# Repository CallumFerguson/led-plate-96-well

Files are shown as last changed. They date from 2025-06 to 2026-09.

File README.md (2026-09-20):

# led-plate-96-well

control genetically engineered cells with light

## Description

PCB for running optogenetic experiments. Designed to shine light through the bottom of [clear bottom 96 well plates](https://www.thermofisher.com/order/catalog/product/152037) and activate light gated ion channels in genetically engineered cells.

Used for experiments in controlling cell maturation by changing the cell's resting membrane potential.

## PCB

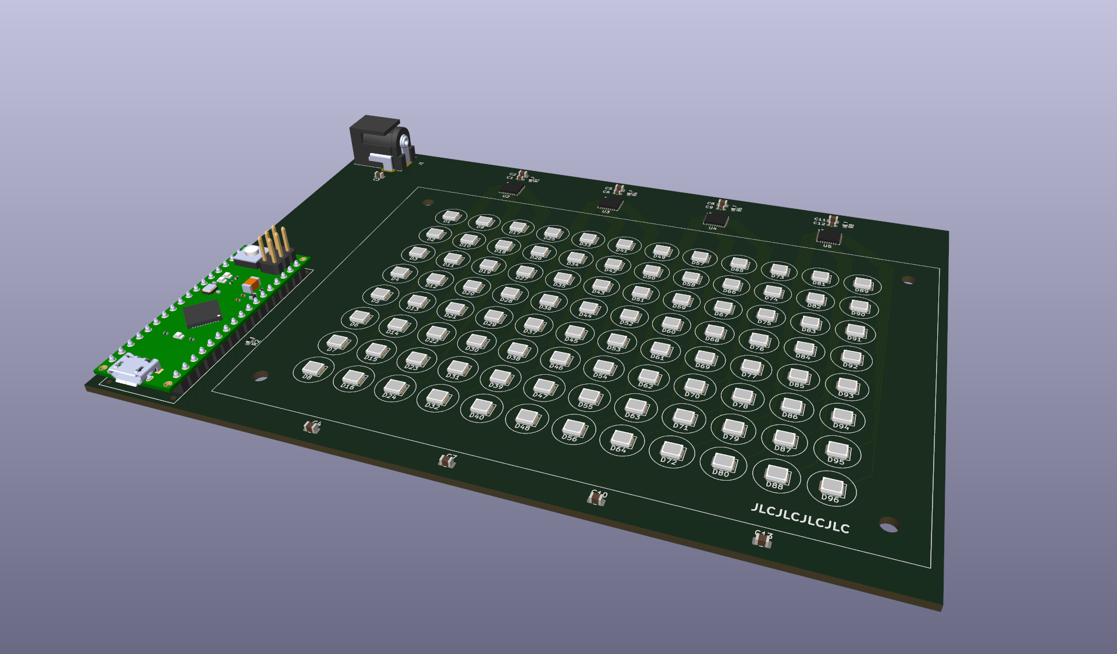
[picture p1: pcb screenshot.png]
3D view of the 96-well LED plate PCB


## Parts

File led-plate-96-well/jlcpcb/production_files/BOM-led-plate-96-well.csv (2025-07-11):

Comment | Designator | Footprint | LCSC | Quantity
2.49kΩ | R1,R4,R6,R8 | R_0402_1005Metric | C102924 | 4
100nF | C1,C12,C6,C9 | C_0603_1608Metric | C14663 | 4
100uF | C3 | C_1206_3216Metric | C15008 | 1
10uF | C10,C11,C13,C2,C4,C5,C7,C8 | C_0805_2012Metric | C15850 | 8
TLC5947RHB | U2,U3,U4,U5 | QFN-32-1EP_5x5mm_P0.5mm_EP3.45x3.45mm | C181402 | 4
10kΩ | R2 | R_0603_1608Metric | C25804 | 1
LED | D1,D10,D11,D12,D13,D14,D15,D16,D17,D18,D19,D2,D20,D21,D22,D23,D24,D25,D26,D27,D28,D29,D3,D30,D31,D32,D33,D34,D35,D36,D37,D38,D39,D4,D40,D41,D42,D43,D44,D45,D46,D47,D48,D49,D5,D50,D51,D52,D53,D54,D55,D56,D57,D58,D59,D6,D60,D61,D62,D63,D64,D65,D66,D67,D68,D69,D7,D70,D71,D72,D73,D74,D75,D76,D77,D78,D79,D8,D80,D81,D82,D83,D84,D85,D86,D87,D88,D89,D9,D90,D91,D92,D93,D94,D95,D96 | LED_PLCC_2835 | C440449 | 96

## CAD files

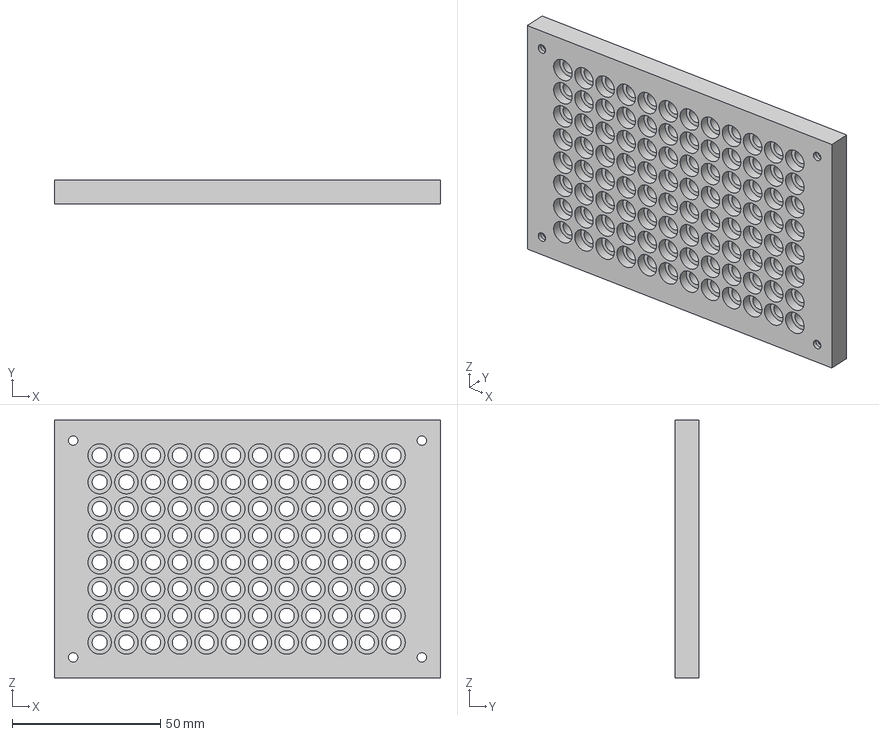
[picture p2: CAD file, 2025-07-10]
led-plate-96-well/components/plate_adapater_96_well/Opto Plate v10.step
130.0 x 8.13 x 86.8 mm

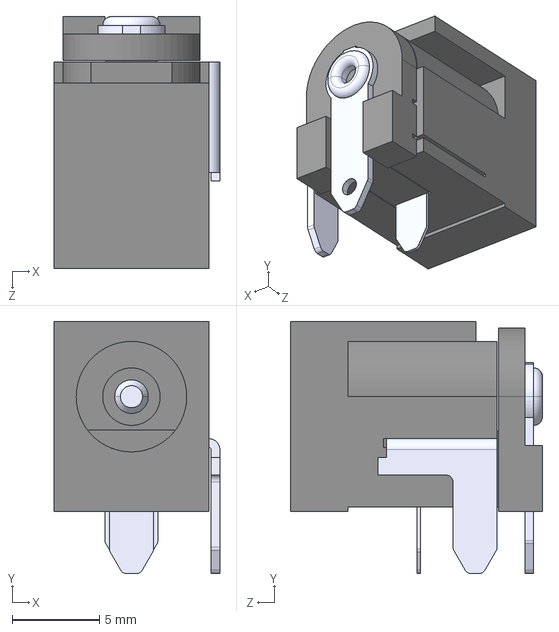
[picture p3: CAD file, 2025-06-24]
led-plate-96-well/components/RAPC722X/RAPC722X.step
9.53 x 14.5 x 14.5 mm

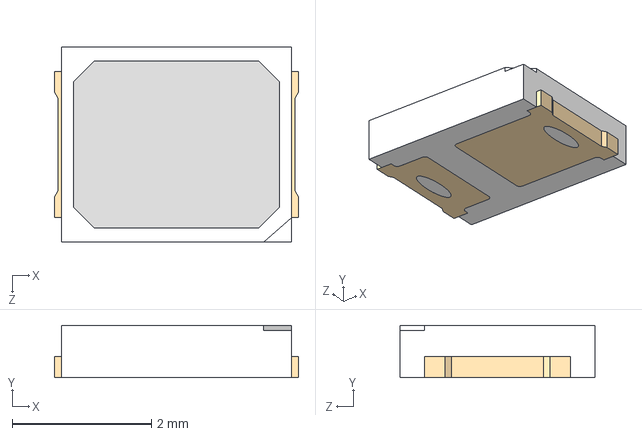
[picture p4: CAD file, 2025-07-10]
led-plate-96-well/components/SMD2835/SMD2835.STEP
3.50 x 0.75 x 2.80 mm

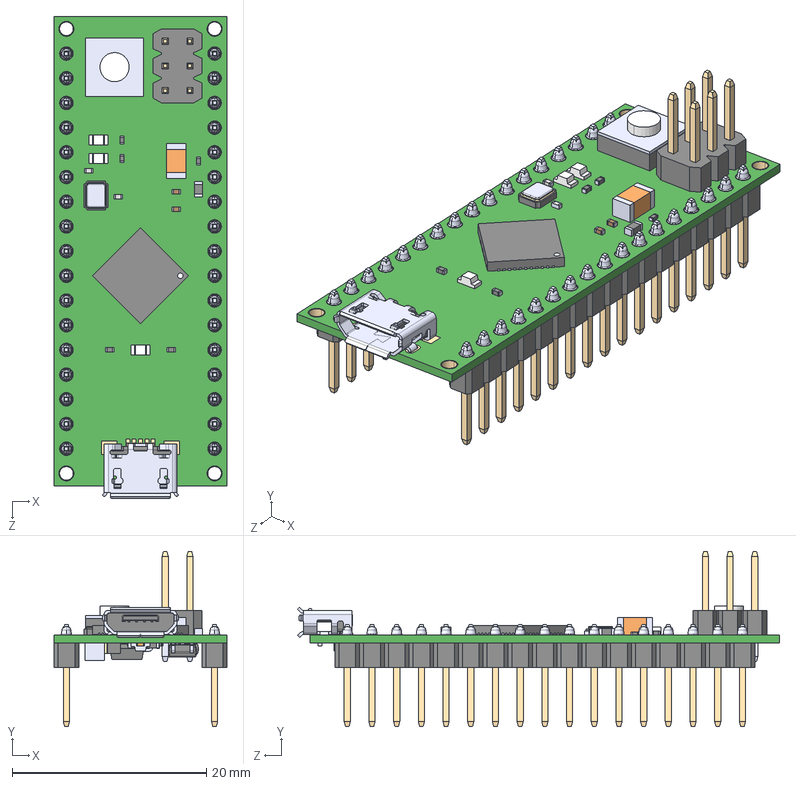
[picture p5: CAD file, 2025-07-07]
led-plate-96-well/components/arduino_micro/A000053.step
17.8 x 18.0 x 49.6 mm
Arduino Micro_Board
10118193-0001LF
ATMEGA32U4-XUMU_ATMEGA32U4-XUMU
CG0603MLC-05E_CG0603MLC-05E x 2
FDN340P
LP2985-33DBVR_LP2985-33DBVR
MC33269ST_MC33269ST
MF-MSMF050-2_MF-MSMF050-2
PMV48XP_PMV48XP

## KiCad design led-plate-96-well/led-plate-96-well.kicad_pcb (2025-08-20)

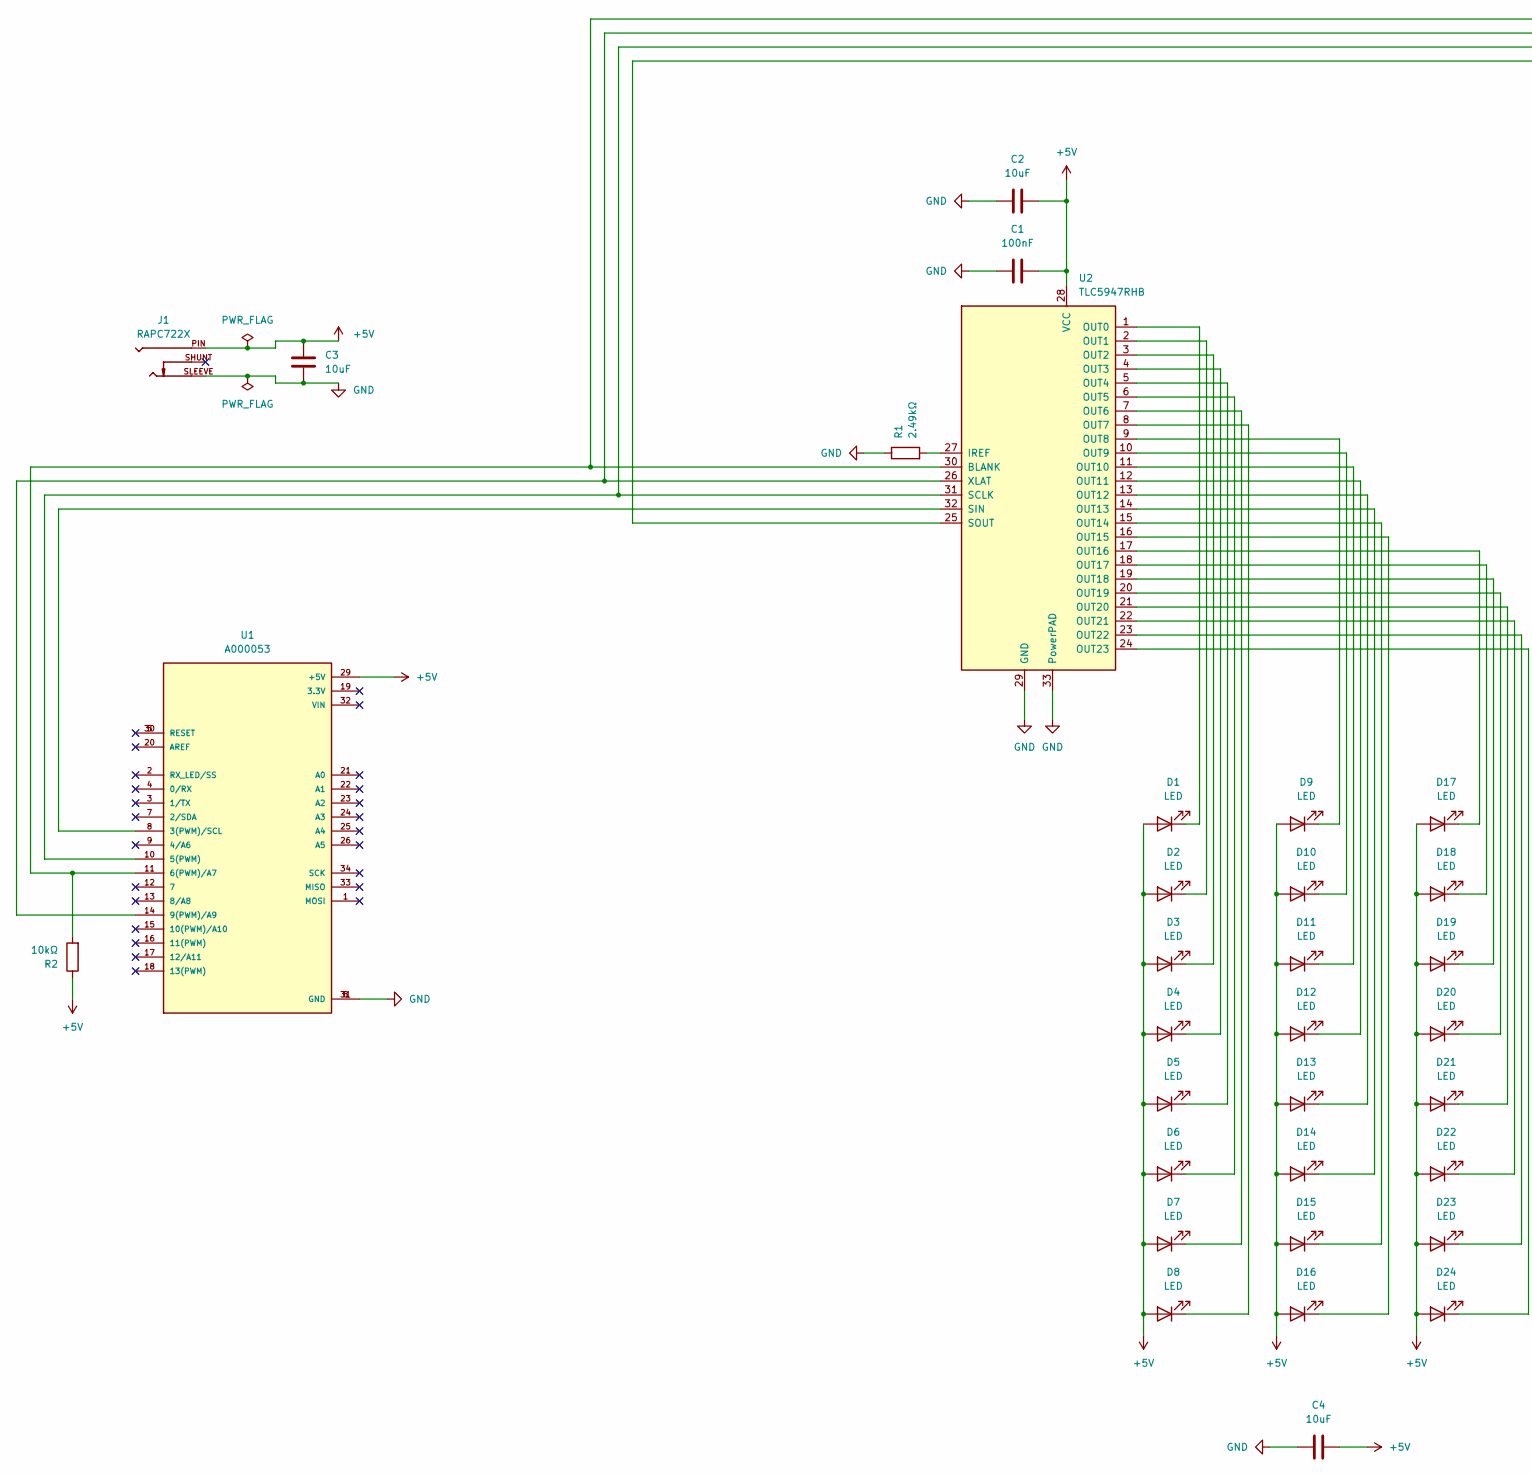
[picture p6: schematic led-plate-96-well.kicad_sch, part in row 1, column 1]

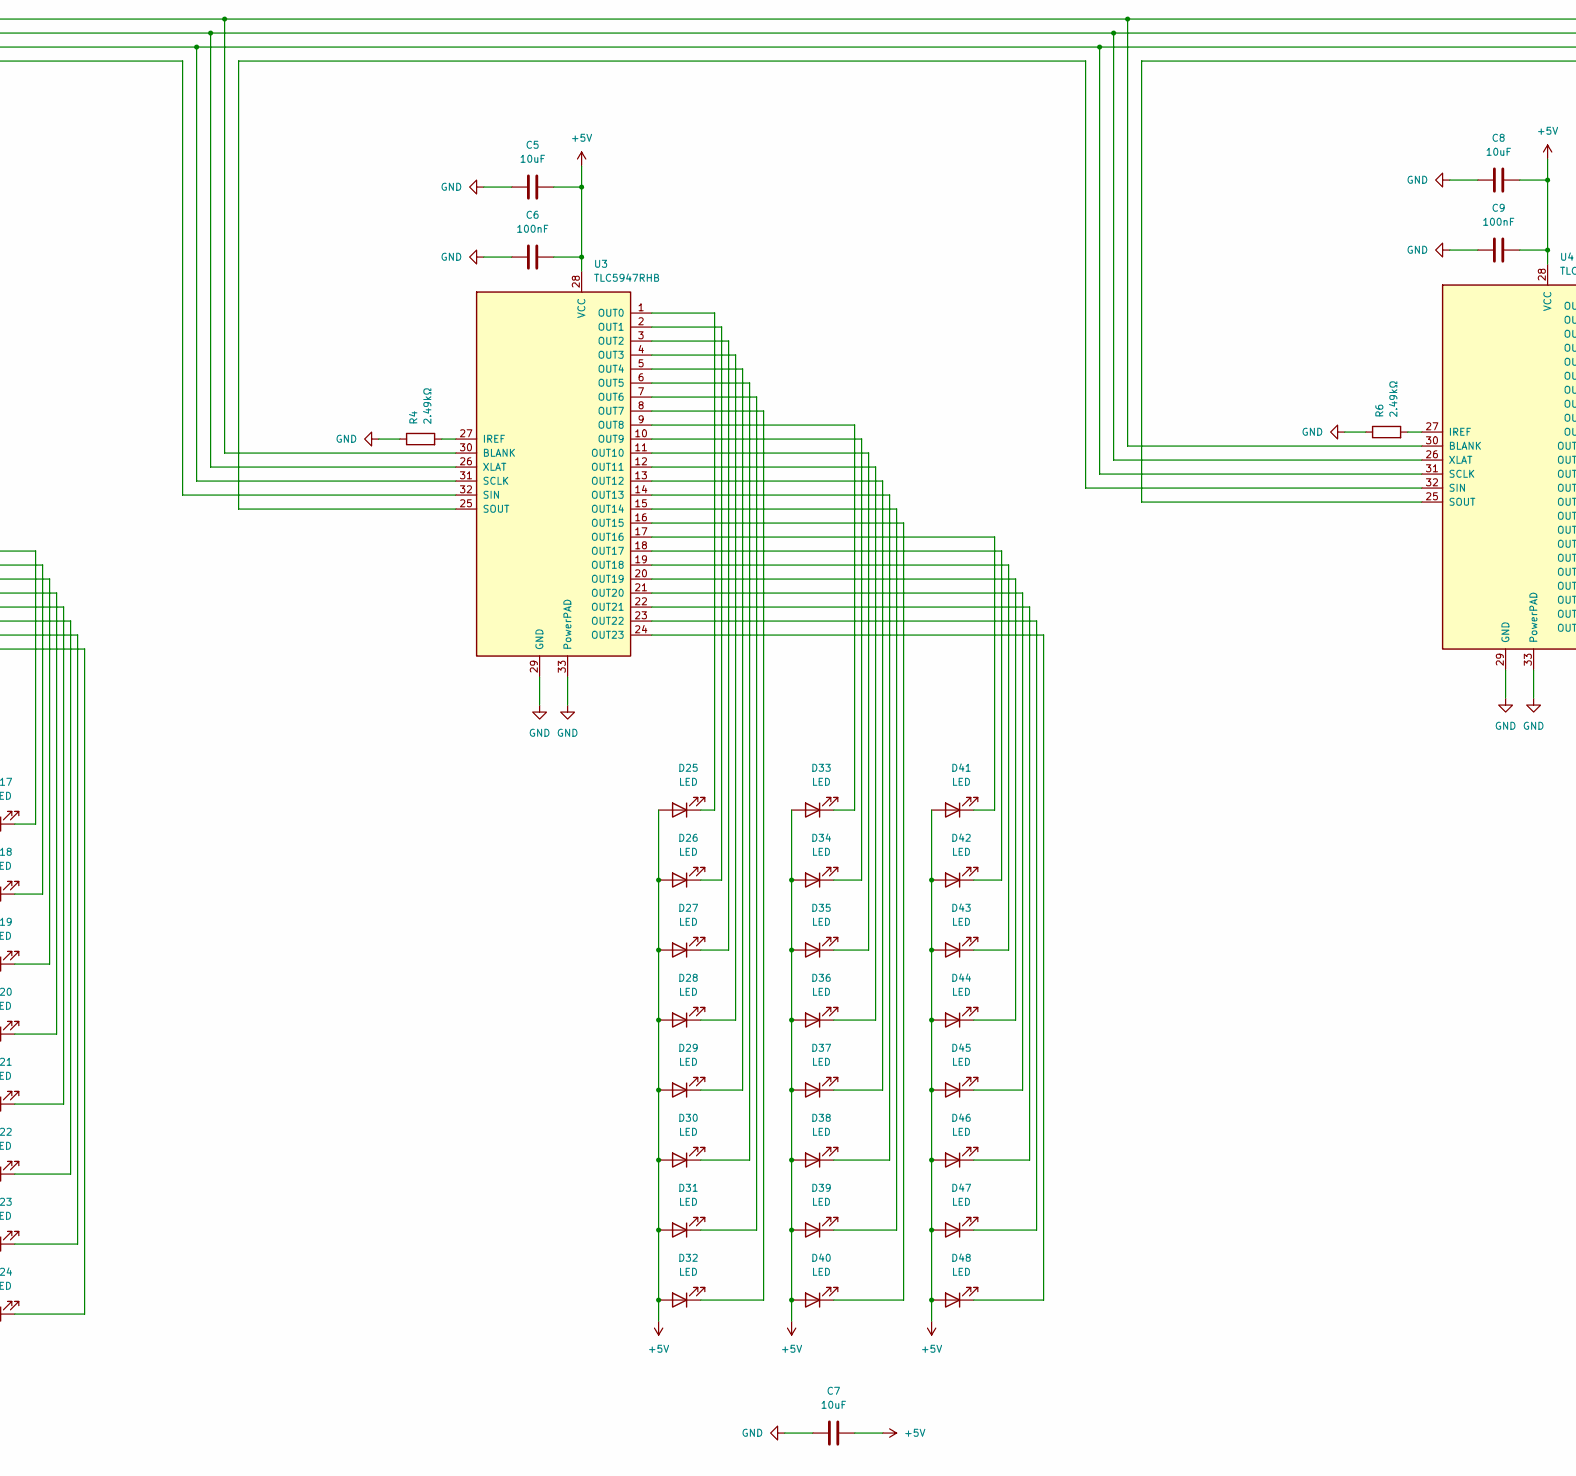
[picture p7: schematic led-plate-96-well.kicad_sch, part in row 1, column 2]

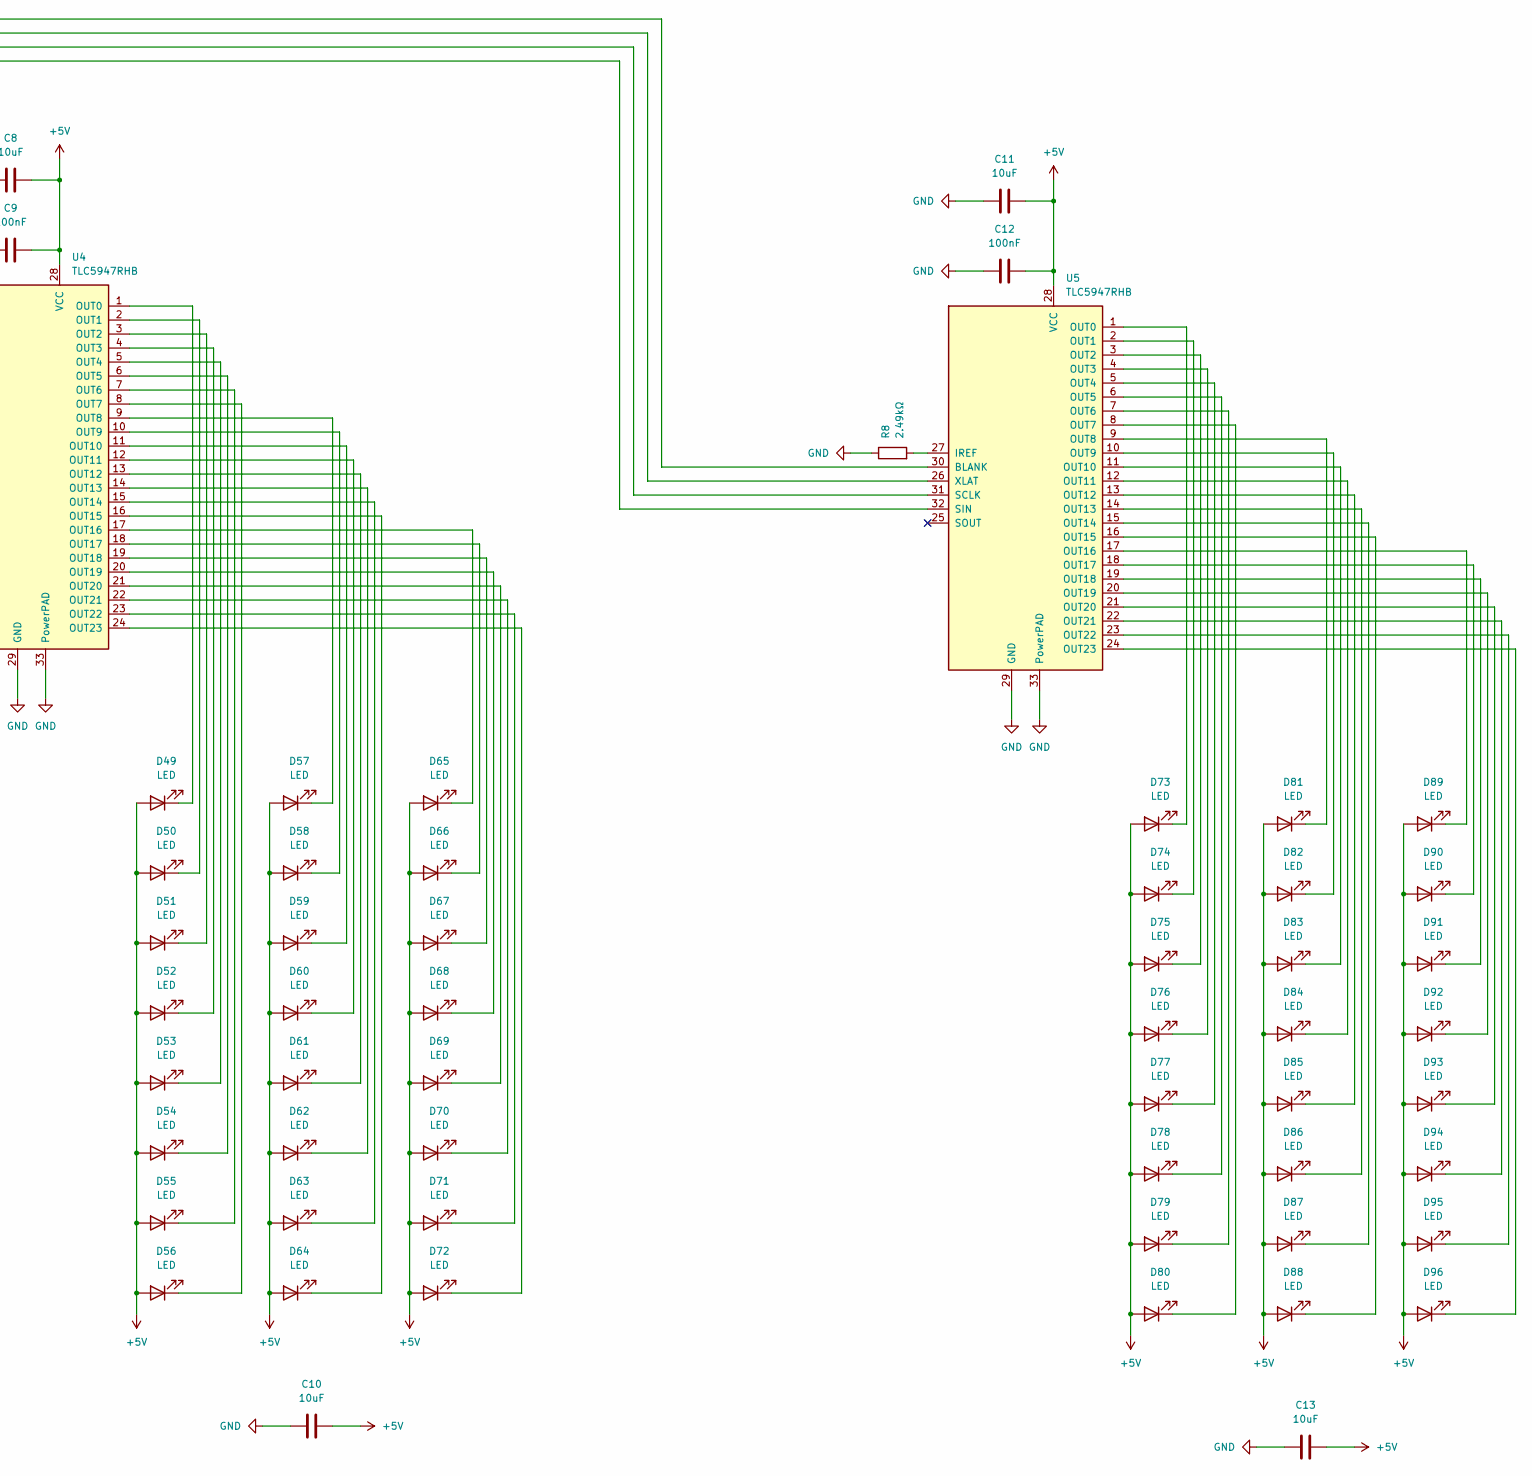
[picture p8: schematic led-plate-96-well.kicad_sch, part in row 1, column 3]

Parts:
C1, C6, C9, C12: 100nF; C_0603_1608Metric; part number CC0603KRX7R9BB104
C2, C3, C4, C5, C7, C8, C10, C11, C13: 10uF; C_0805_2012Metric; part number CL21A106KAYNNNE
D1, D2, D3, D4, D5, D6, D7, D8, D9, D10, D11, D12, D13, D14, D15, D16, D17, D18, D19, D20, D21, D22, D23, D24, D25, D26, D27, D28, D29, D30, D31, D32, D33, D34, D35, D36, D37, D38, D39, D40, D41, D42, D43, D44, D45, D46, D47, D48, D49, D50, D51, D52, D53, D54, D55, D56, D57, D58, D59, D60, D61, D62, D63, D64, D65, D66, D67, D68, D69, D70, D71, D72, D73, D74, D75, D76, D77, D78, D79, D80, D81, D82, D83, D84, D85, D86, D87, D88, D89, D90, D91, D92, D93, D94, D95, D96: LED; LED_PLCC_2835; part number TJ-S2835UG2W8TLC6B-A5
J1: RAPC722X; SWITCHCRAFT_RAPC722X; PARTREV A
R1, R4, R6, R8: 2.49kΩ; R_0603_1608Metric; part number RC0603FR-072K49L
R2: 10kΩ; R_0603_1608Metric; part number 0603WAF1002T5E
U1: A000053; PARTREV N/A
U2, U3, U4, U5: TLC5947RHB; QFN-32-1EP_5x5mm_P0.5mm_EP3.45x3.45mm

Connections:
+5V: C1.2, C2.2, C3.1, C4.2, C5.2, C6.2, C7.2, C8.2, C9.2, C10.2, C11.2, C12.2, C13.2, D1.2 (A), D2.2 (A), D3.2 (A), D4.2 (A), D5.2 (A), D6.2 (A), D7.2 (A), D8.2 (A), D9.2 (A), D10.2 (A), D11.2 (A), D12.2 (A), D13.2 (A), D14.2 (A), D15.2 (A), D16.2 (A), D17.2 (A), D18.2 (A), D19.2 (A), D20.2 (A), D21.2 (A), D22.2 (A), D23.2 (A), D24.2 (A), D25.2 (A), D26.2 (A), D27.2 (A), D28.2 (A), D29.2 (A), D30.2 (A), D31.2 (A), D32.2 (A), D33.2 (A), D34.2 (A), D35.2 (A), D36.2 (A), D37.2 (A), D38.2 (A), D39.2 (A), D40.2 (A), D41.2 (A), D42.2 (A), D43.2 (A), D44.2 (A), D45.2 (A), D46.2 (A), D47.2 (A), D48.2 (A), D49.2 (A), D50.2 (A), D51.2 (A), D52.2 (A), D53.2 (A), D54.2 (A), D55.2 (A), D56.2 (A), D57.2 (A), D58.2 (A), D59.2 (A), D60.2 (A), D61.2 (A), D62.2 (A), D63.2 (A), D64.2 (A), D65.2 (A), D66.2 (A), D67.2 (A), D68.2 (A), D69.2 (A), D70.2 (A), D71.2 (A), D72.2 (A), D73.2 (A), D74.2 (A), D75.2 (A), D76.2 (A), D77.2 (A), D78.2 (A), D79.2 (A), D80.2 (A), D81.2 (A), D82.2 (A), D83.2 (A), D84.2 (A), D85.2 (A), D86.2 (A), D87.2 (A), D88.2 (A), D89.2 (A), D90.2 (A), D91.2 (A), D92.2 (A), D93.2 (A), D94.2 (A), D95.2 (A), D96.2 (A), J1.PIN, R2.1, U1.29 (+5V), U2.28 (VCC), U3.28 (VCC), U4.28 (VCC), U5.28 (VCC)
GND: C1.1, C2.1, C3.2, C4.1, C5.1, C6.1, C7.1, C8.1, C9.1, C10.1, C11.1, C12.1, C13.1, J1.SLEEVE, R1.1, R4.1, R6.1, R8.1, U1.6 (GND), U1.31 (GND), U2.29 (GND), U2.33 (PowerPAD), U3.29 (GND), U3.33 (PowerPAD), U4.29 (GND), U4.33 (PowerPAD), U5.29 (GND), U5.33 (PowerPAD)
unnamed: D1.1 (K), U2.1 (OUT0)
unnamed: D2.1 (K), U2.2 (OUT1)
unnamed: D3.1 (K), U2.3 (OUT2)
unnamed: D4.1 (K), U2.4 (OUT3)
unnamed: D5.1 (K), U2.5 (OUT4)
unnamed: D6.1 (K), U2.6 (OUT5)
unnamed: D7.1 (K), U2.7 (OUT6)
unnamed: D8.1 (K), U2.8 (OUT7)
unnamed: D9.1 (K), U2.9 (OUT8)
unnamed: D10.1 (K), U2.10 (OUT9)
unnamed: D11.1 (K), U2.11 (OUT10)
unnamed: D12.1 (K), U2.12 (OUT11)
unnamed: D13.1 (K), U2.13 (OUT12)
unnamed: D14.1 (K), U2.14 (OUT13)
unnamed: D15.1 (K), U2.15 (OUT14)
unnamed: D16.1 (K), U2.16 (OUT15)
unnamed: D17.1 (K), U2.17 (OUT16)
unnamed: D18.1 (K), U2.18 (OUT17)
unnamed: D19.1 (K), U2.19 (OUT18)
unnamed: D20.1 (K), U2.20 (OUT19)
unnamed: D21.1 (K), U2.21 (OUT20)
unnamed: D22.1 (K), U2.22 (OUT21)
unnamed: D23.1 (K), U2.23 (OUT22)
unnamed: D24.1 (K), U2.24 (OUT23)
unnamed: D25.1 (K), U3.1 (OUT0)
unnamed: D26.1 (K), U3.2 (OUT1)
unnamed: D27.1 (K), U3.3 (OUT2)
unnamed: D28.1 (K), U3.4 (OUT3)
unnamed: D29.1 (K), U3.5 (OUT4)
unnamed: D30.1 (K), U3.6 (OUT5)
unnamed: D31.1 (K), U3.7 (OUT6)
unnamed: D32.1 (K), U3.8 (OUT7)
unnamed: D33.1 (K), U3.9 (OUT8)
unnamed: D34.1 (K), U3.10 (OUT9)
unnamed: D35.1 (K), U3.11 (OUT10)
unnamed: D36.1 (K), U3.12 (OUT11)
unnamed: D37.1 (K), U3.13 (OUT12)
unnamed: D38.1 (K), U3.14 (OUT13)
unnamed: D39.1 (K), U3.15 (OUT14)
unnamed: D40.1 (K), U3.16 (OUT15)
unnamed: D41.1 (K), U3.17 (OUT16)
unnamed: D42.1 (K), U3.18 (OUT17)
unnamed: D43.1 (K), U3.19 (OUT18)
unnamed: D44.1 (K), U3.20 (OUT19)
unnamed: D45.1 (K), U3.21 (OUT20)
unnamed: D46.1 (K), U3.22 (OUT21)
unnamed: D47.1 (K), U3.23 (OUT22)
unnamed: D48.1 (K), U3.24 (OUT23)
unnamed: D49.1 (K), U4.1 (OUT0)
unnamed: D50.1 (K), U4.2 (OUT1)
unnamed: D51.1 (K), U4.3 (OUT2)
unnamed: D52.1 (K), U4.4 (OUT3)
unnamed: D53.1 (K), U4.5 (OUT4)
unnamed: D54.1 (K), U4.6 (OUT5)
unnamed: D55.1 (K), U4.7 (OUT6)
unnamed: D56.1 (K), U4.8 (OUT7)
unnamed: D57.1 (K), U4.9 (OUT8)
unnamed: D58.1 (K), U4.10 (OUT9)
unnamed: D59.1 (K), U4.11 (OUT10)
unnamed: D60.1 (K), U4.12 (OUT11)
unnamed: D61.1 (K), U4.13 (OUT12)
unnamed: D62.1 (K), U4.14 (OUT13)
unnamed: D63.1 (K), U4.15 (OUT14)
unnamed: D64.1 (K), U4.16 (OUT15)
unnamed: D65.1 (K), U4.17 (OUT16)
unnamed: D66.1 (K), U4.18 (OUT17)
unnamed: D67.1 (K), U4.19 (OUT18)
unnamed: D68.1 (K), U4.20 (OUT19)
unnamed: D69.1 (K), U4.21 (OUT20)
unnamed: D70.1 (K), U4.22 (OUT21)
unnamed: D71.1 (K), U4.23 (OUT22)
unnamed: D72.1 (K), U4.24 (OUT23)
unnamed: D73.1 (K), U5.1 (OUT0)
unnamed: D74.1 (K), U5.2 (OUT1)
unnamed: D75.1 (K), U5.3 (OUT2)
unnamed: D76.1 (K), U5.4 (OUT3)
unnamed: D77.1 (K), U5.5 (OUT4)
unnamed: D78.1 (K), U5.6 (OUT5)
unnamed: D79.1 (K), U5.7 (OUT6)
unnamed: D80.1 (K), U5.8 (OUT7)
unnamed: D81.1 (K), U5.9 (OUT8)
unnamed: D82.1 (K), U5.10 (OUT9)
unnamed: D83.1 (K), U5.11 (OUT10)
unnamed: D84.1 (K), U5.12 (OUT11)
unnamed: D85.1 (K), U5.13 (OUT12)
unnamed: D86.1 (K), U5.14 (OUT13)
unnamed: D87.1 (K), U5.15 (OUT14)
unnamed: D88.1 (K), U5.16 (OUT15)
unnamed: D89.1 (K), U5.17 (OUT16)
unnamed: D90.1 (K), U5.18 (OUT17)
unnamed: D91.1 (K), U5.19 (OUT18)
unnamed: D92.1 (K), U5.20 (OUT19)
unnamed: D93.1 (K), U5.21 (OUT20)
unnamed: D94.1 (K), U5.22 (OUT21)
unnamed: D95.1 (K), U5.23 (OUT22)
unnamed: D96.1 (K), U5.24 (OUT23)
unnamed: U1.8 (3(PWM)/SCL), U2.32 (SIN)
unnamed: U1.10 (5(PWM)), U2.31 (SCLK), U3.31 (SCLK), U4.31 (SCLK), U5.31 (SCLK)
unnamed: R2.2, U1.11 (6(PWM)/A7), U2.30 (BLANK), U3.30 (BLANK), U4.30 (BLANK), U5.30 (BLANK)
unnamed: U1.14 (9(PWM)/A9), U2.26 (XLAT), U3.26 (XLAT), U4.26 (XLAT), U5.26 (XLAT)
unnamed: R1.2, U2.27 (IREF)
unnamed: U2.25 (SOUT), U3.32 (SIN)
unnamed: R4.2, U3.27 (IREF)
unnamed: U3.25 (SOUT), U4.32 (SIN)
unnamed: R6.2, U4.27 (IREF)
unnamed: U4.25 (SOUT), U5.32 (SIN)
unnamed: R8.2, U5.27 (IREF)

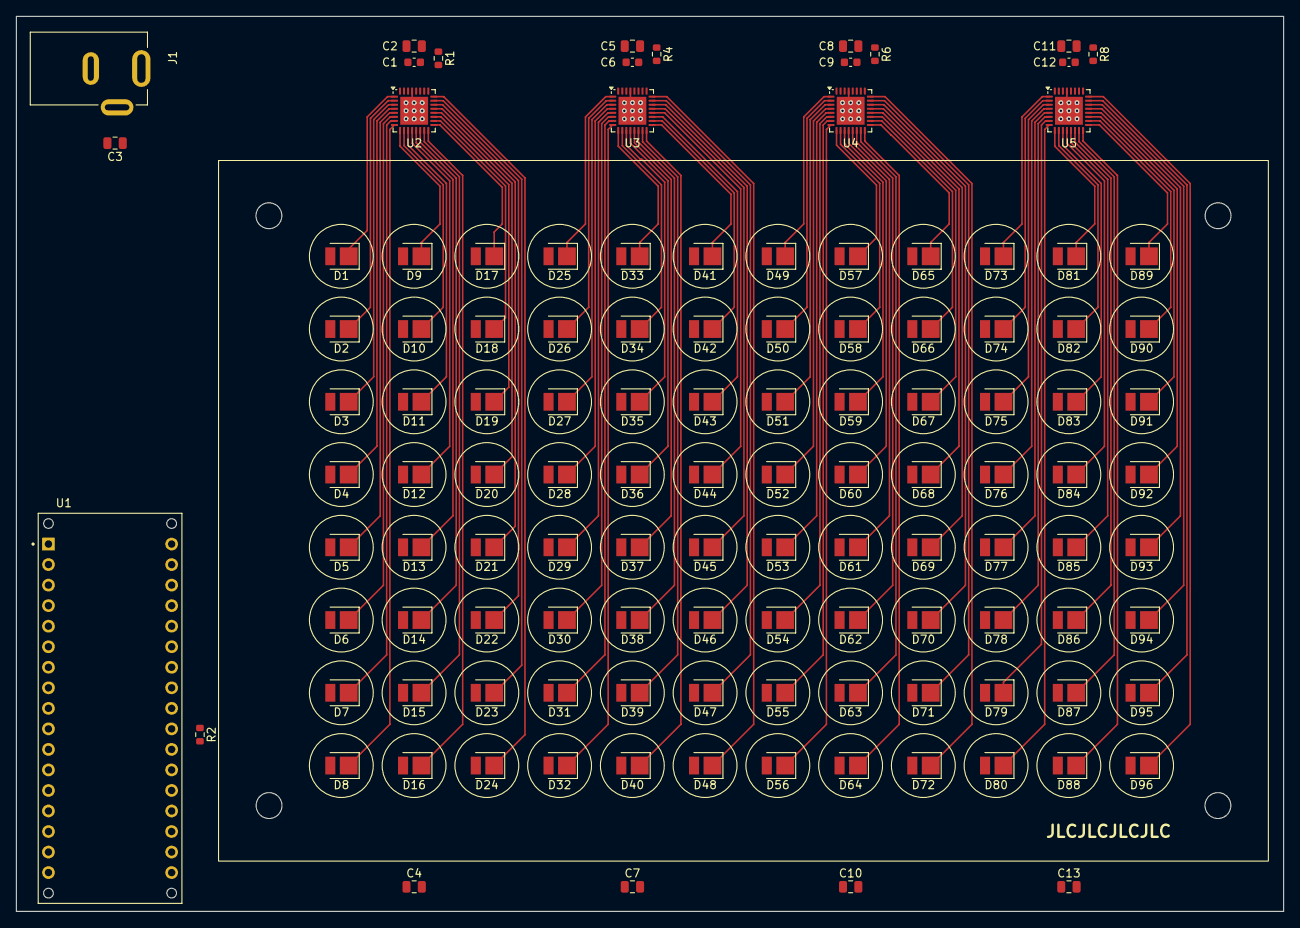
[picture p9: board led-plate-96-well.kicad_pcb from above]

Board: 2 copper layers, 156.8 x 110.7 mm, 120 parts (0 on the bottom side), 109 nets.

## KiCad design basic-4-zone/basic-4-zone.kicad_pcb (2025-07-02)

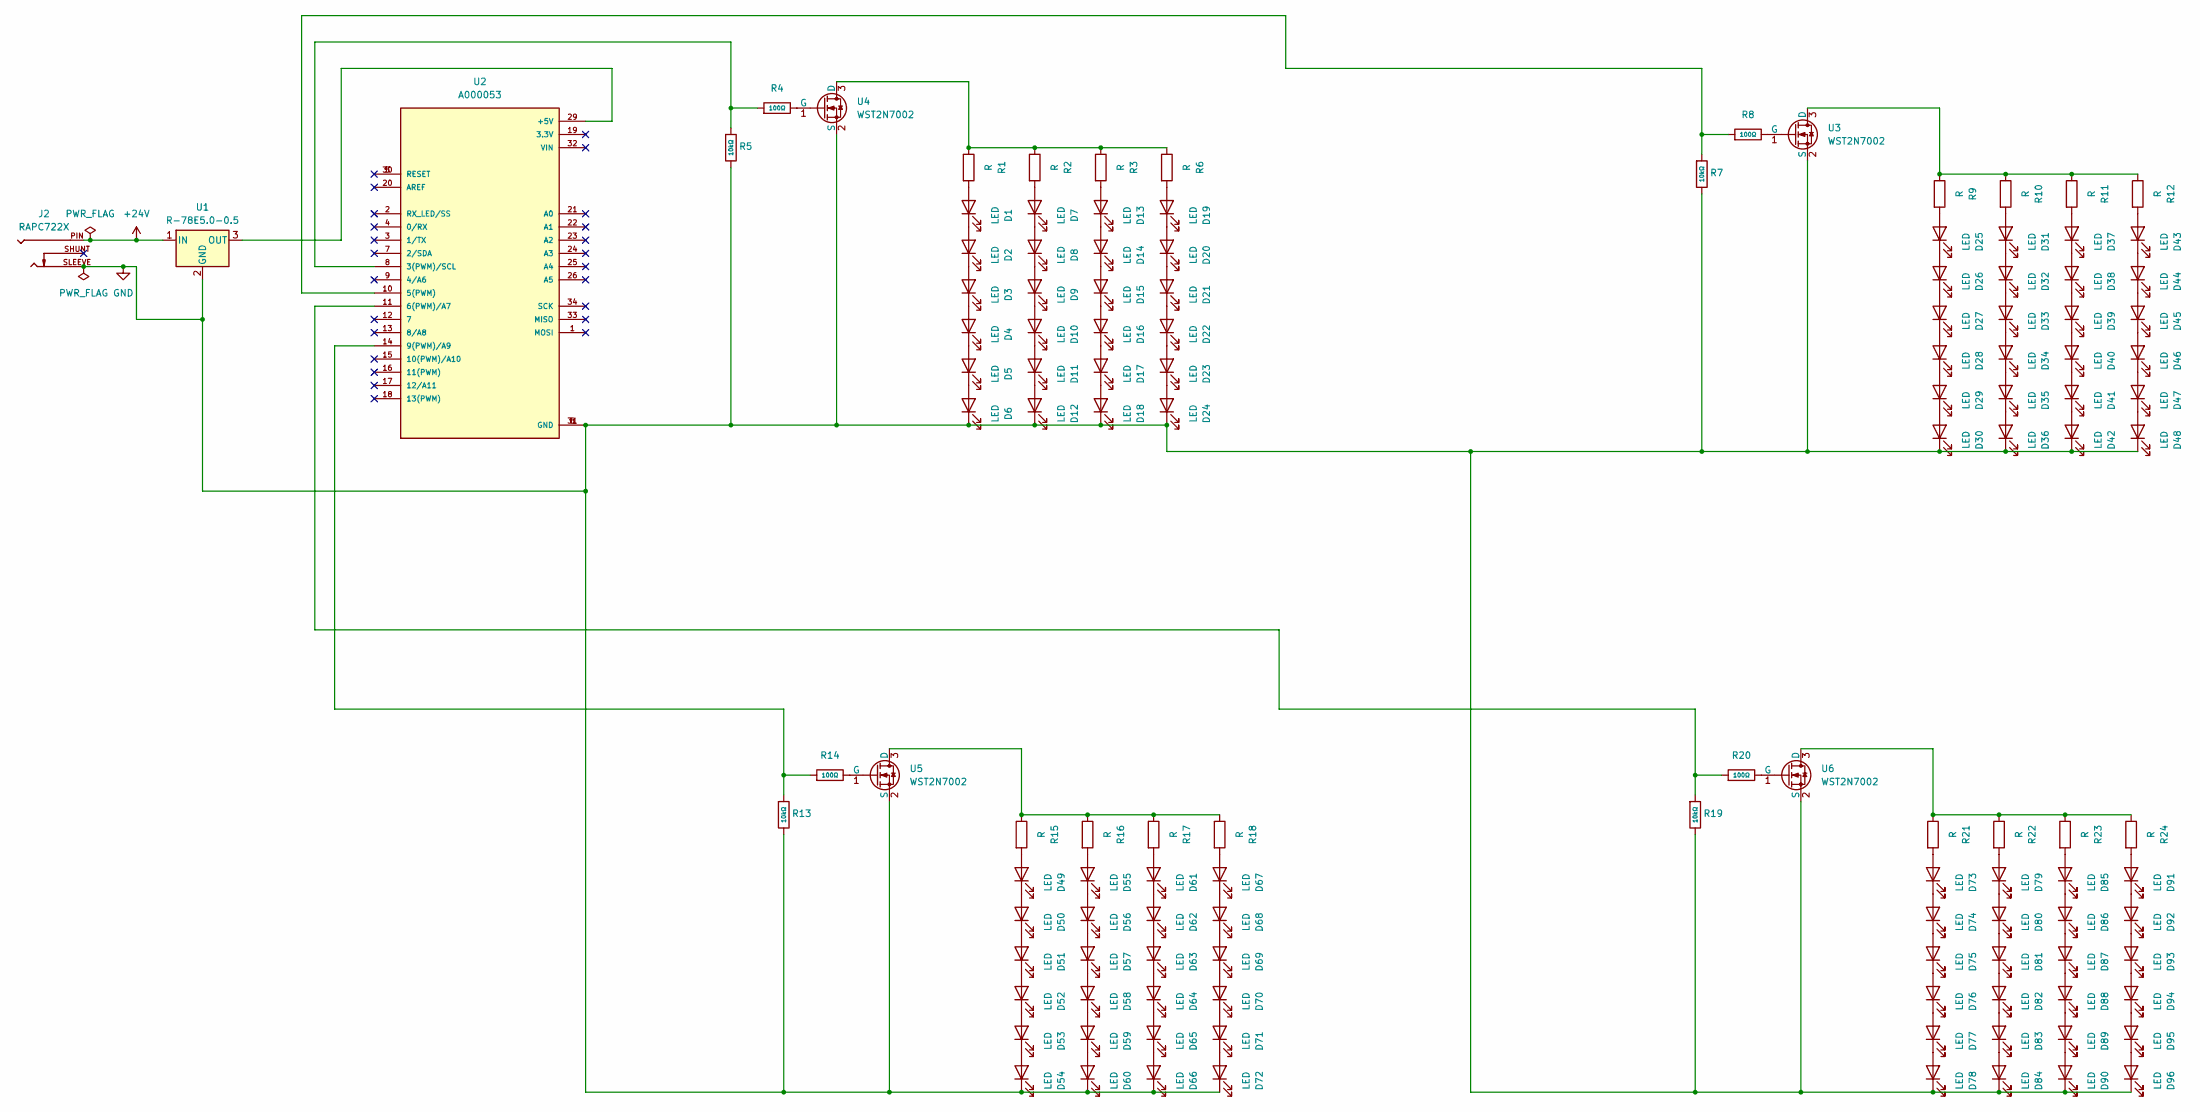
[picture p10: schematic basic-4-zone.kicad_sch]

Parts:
D1, D2, D3, D4, D5, D6, D7, D8, D9, D10, D11, D12, D13, D14, D15, D16, D17, D18, D19, D20, D21, D22, D23, D24, D25, D26, D27, D28, D29, D30, D31, D32, D33, D34, D35, D36, D37, D38, D39, D40, D41, D42, D43, D44, D45, D46, D47, D48, D49, D50, D51, D52, D53, D54, D55, D56, D57, D58, D59, D60, D61, D62, D63, D64, D65, D66, D67, D68, D69, D70, D71, D72, D73, D74, D75, D76, D77, D78, D79, D80, D81, D82, D83, D84, D85, D86, D87, D88, D89, D90, D91, D92, D93, D94, D95, D96: LED; LED_Luminus_MP-3030-1100_3.0x3.0mm
J2: RAPC722X; SWITCHCRAFT_RAPC722X; PARTREV A
R1, R2, R3, R6, R9, R10, R11, R12, R15, R16, R17, R18, R21, R22, R23, R24: R; R_1210_3225Metric
R4, R8, R14, R20: 100Ω; R_1206; Overload Voltage (Max) 200V; Tolerance ±1%; Part 1206W4F100LT5E; LCSC C25334
R5, R7, R13, R19: 10kΩ; R_1206; Overload Voltage (Max) 200V; Tolerance ±1%; Part 1206W4F1002T5E; LCSC C17902
U1: R-78E5.0-0.5; Converter_DCDC_RECOM_R-78E-0.5_THT
U2: A000053; ARDUINO_A000053; PARTREV N/A
U3, U4, U5, U6: WST2N7002; SOT-23

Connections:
+24V: J2.PIN, U1.1 (IN)
GND: D6.1 (K), D12.1 (K), D18.1 (K), D24.1 (K), D30.1 (K), D36.1 (K), D42.1 (K), D48.1 (K), D54.1 (K), D60.1 (K), D66.1 (K), D72.1 (K), D78.1 (K), D84.1 (K), D90.1 (K), D96.1 (K), J2.SLEEVE, R5.2, R7.2, R13.2, R19.2, U1.2 (GND), U2.6 (GND), U2.31 (GND), U3.2 (S), U4.2 (S), U5.2 (S), U6.2 (S)
unnamed: D1.2 (A), R1.2
unnamed: D1.1 (K), D2.2 (A)
unnamed: D2.1 (K), D3.2 (A)
unnamed: D3.1 (K), D4.2 (A)
unnamed: D4.1 (K), D5.2 (A)
unnamed: D5.1 (K), D6.2 (A)
unnamed: D7.2 (A), R2.2
unnamed: D7.1 (K), D8.2 (A)
unnamed: D8.1 (K), D9.2 (A)
unnamed: D9.1 (K), D10.2 (A)
unnamed: D10.1 (K), D11.2 (A)
unnamed: D11.1 (K), D12.2 (A)
unnamed: D13.2 (A), R3.2
unnamed: D13.1 (K), D14.2 (A)
unnamed: D14.1 (K), D15.2 (A)
unnamed: D15.1 (K), D16.2 (A)
unnamed: D16.1 (K), D17.2 (A)
unnamed: D17.1 (K), D18.2 (A)
unnamed: D19.2 (A), R6.2
unnamed: D19.1 (K), D20.2 (A)
unnamed: D20.1 (K), D21.2 (A)
unnamed: D21.1 (K), D22.2 (A)
unnamed: D22.1 (K), D23.2 (A)
unnamed: D23.1 (K), D24.2 (A)
unnamed: D25.2 (A), R9.2
unnamed: D25.1 (K), D26.2 (A)
unnamed: D26.1 (K), D27.2 (A)
unnamed: D27.1 (K), D28.2 (A)
unnamed: D28.1 (K), D29.2 (A)
unnamed: D29.1 (K), D30.2 (A)
unnamed: D31.2 (A), R10.2
unnamed: D31.1 (K), D32.2 (A)
unnamed: D32.1 (K), D33.2 (A)
unnamed: D33.1 (K), D34.2 (A)
unnamed: D34.1 (K), D35.2 (A)
unnamed: D35.1 (K), D36.2 (A)
unnamed: D37.2 (A), R11.2
unnamed: D37.1 (K), D38.2 (A)
unnamed: D38.1 (K), D39.2 (A)
unnamed: D39.1 (K), D40.2 (A)
unnamed: D40.1 (K), D41.2 (A)
unnamed: D41.1 (K), D42.2 (A)
unnamed: D43.2 (A), R12.2
unnamed: D43.1 (K), D44.2 (A)
unnamed: D44.1 (K), D45.2 (A)
unnamed: D45.1 (K), D46.2 (A)
unnamed: D46.1 (K), D47.2 (A)
unnamed: D47.1 (K), D48.2 (A)
unnamed: D49.2 (A), R15.2
unnamed: D49.1 (K), D50.2 (A)
unnamed: D50.1 (K), D51.2 (A)
unnamed: D51.1 (K), D52.2 (A)
unnamed: D52.1 (K), D53.2 (A)
unnamed: D53.1 (K), D54.2 (A)
unnamed: D55.2 (A), R16.2
unnamed: D55.1 (K), D56.2 (A)
unnamed: D56.1 (K), D57.2 (A)
unnamed: D57.1 (K), D58.2 (A)
unnamed: D58.1 (K), D59.2 (A)
unnamed: D59.1 (K), D60.2 (A)
unnamed: D61.2 (A), R17.2
unnamed: D61.1 (K), D62.2 (A)
unnamed: D62.1 (K), D63.2 (A)
unnamed: D63.1 (K), D64.2 (A)
unnamed: D64.1 (K), D65.2 (A)
unnamed: D65.1 (K), D66.2 (A)
unnamed: D67.2 (A), R18.2
unnamed: D67.1 (K), D68.2 (A)
unnamed: D68.1 (K), D69.2 (A)
unnamed: D69.1 (K), D70.2 (A)
unnamed: D70.1 (K), D71.2 (A)
unnamed: D71.1 (K), D72.2 (A)
unnamed: D73.2 (A), R21.2
unnamed: D73.1 (K), D74.2 (A)
unnamed: D74.1 (K), D75.2 (A)
unnamed: D75.1 (K), D76.2 (A)
unnamed: D76.1 (K), D77.2 (A)
unnamed: D77.1 (K), D78.2 (A)
unnamed: D79.2 (A), R22.2
unnamed: D79.1 (K), D80.2 (A)
unnamed: D80.1 (K), D81.2 (A)
unnamed: D81.1 (K), D82.2 (A)
unnamed: D82.1 (K), D83.2 (A)
unnamed: D83.1 (K), D84.2 (A)
unnamed: D85.2 (A), R23.2
unnamed: D85.1 (K), D86.2 (A)
unnamed: D86.1 (K), D87.2 (A)
unnamed: D87.1 (K), D88.2 (A)
unnamed: D88.1 (K), D89.2 (A)
unnamed: D89.1 (K), D90.2 (A)
unnamed: D91.2 (A), R24.2
unnamed: D91.1 (K), D92.2 (A)
unnamed: D92.1 (K), D93.2 (A)
unnamed: D93.1 (K), D94.2 (A)
unnamed: D94.1 (K), D95.2 (A)
unnamed: D95.1 (K), D96.2 (A)
unnamed: U1.3 (OUT), U2.29 (+5V)
unnamed: R4.1, R5.1, U2.8 (3(PWM)/SCL)
unnamed: R7.1, R8.1, U2.10 (5(PWM))
unnamed: R19.1, R20.1, U2.11 (6(PWM)/A7)
unnamed: R13.1, R14.1, U2.14 (9(PWM)/A9)
unnamed: R9.1, R10.1, R11.1, R12.1, U3.3 (D)
unnamed: R8.2, U3.1 (G)
unnamed: R1.1, R2.1, R3.1, R6.1, U4.3 (D)
unnamed: R4.2, U4.1 (G)
unnamed: R15.1, R16.1, R17.1, R18.1, U5.3 (D)
unnamed: R14.2, U5.1 (G)
unnamed: R21.1, R22.1, R23.1, R24.1, U6.3 (D)
unnamed: R20.2, U6.1 (G)

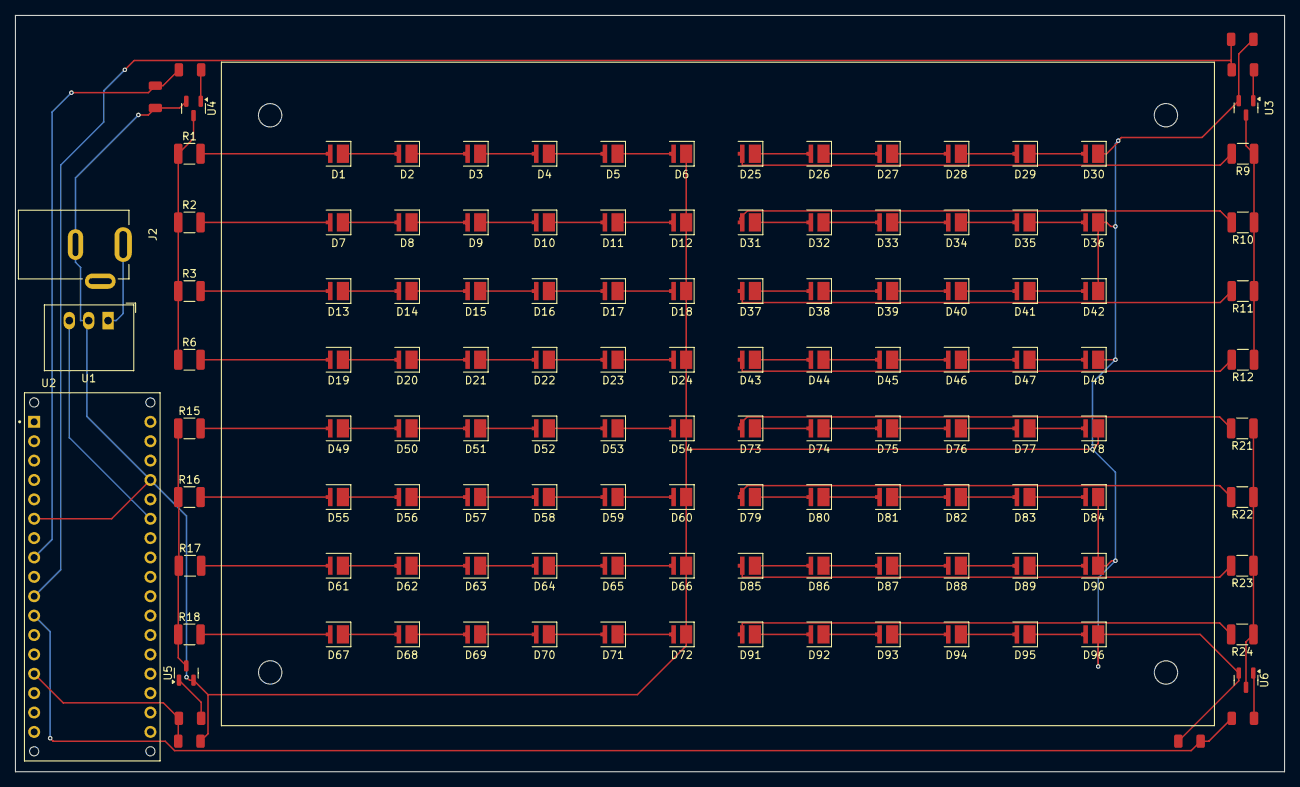
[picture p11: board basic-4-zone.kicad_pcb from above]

Board: 2 copper layers, 166.3 x 99.1 mm, 127 parts (0 on the bottom side), 111 nets.

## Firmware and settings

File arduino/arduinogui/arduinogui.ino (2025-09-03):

#include "Adafruit_TLC5947.h"

#define PIN_DATA 3
#define PIN_CLOCK 5
#define PIN_LATCH 9
#define PIN_BLANK 6

#define NUM_TLC5947 4
constexpr uint16_t NUM_CHANNELS = NUM_TLC5947 * 24;

Adafruit_TLC5947 tlc(NUM_TLC5947, PIN_CLOCK, PIN_DATA, PIN_LATCH);

struct SequenceStep
{
    uint32_t on_ms;            // ON window length
    uint32_t off_ms;           // OFF window length
    uint16_t intensity;        // value to return while ON
    uint32_t loop_duration_ms; // duration to run this step (0 = forever)
};

// Returns current intensity for the sequence.
// - 0 if we're in an OFF window or sequence has ended
// - step.intensity if we're in an ON window
// Safe across millis() rollover.
uint16_t sequenceIntensity(const SequenceStep *steps, size_t count)
{
    uint32_t elapsed = millis(); // rollover-safe elapsed time

    // Walk through steps, subtracting their durations until we find the active one.
    for (size_t i = 0; i < count; ++i)
    {
        const SequenceStep &s = steps[i];
        uint32_t dur = s.loop_duration_ms;

        // If this step is infinite or the remaining time falls within this step, evaluate it.
        if (dur == 0 || elapsed < dur)
        {
            // Edge cases
            if (s.intensity == 0)
                return 0; // explicitly off
            if (s.on_ms == 0)
                return 0; // never turns on
            if (s.off_ms == 0)
                return s.intensity; // always on within this step

            // Regular blinking within the step
            uint64_t period = (uint64_t)s.on_ms + (uint64_t)s.off_ms; // avoid overflow
            if (period == 0)
                return 0; // both zero -> off

            uint64_t phase = (uint64_t)elapsed % period;
            return (phase < s.on_ms) ? s.intensity : 0;
        }

        // Otherwise, move to the next step
        elapsed -= dur;
    }

    // Past the end of all steps -> off
    return 0;
}

// ===== START GENERATED CODE =====

int8_t wellGroup[] = {
    0, 1, -1, -1, -1, -1, -1, -1,
    -1, -1, -1, -1, -1, -1, -1, -1,
    -1, -1, -1, -1, -1, -1, -1, -1,
    -1, -1, -1, -1, -1, -1, -1, -1,
    -1, -1, -1, -1, -1, -1, -1, -1,
    -1, -1, -1, -1, -1, -1, -1, -1,
    -1, -1, -1, -1, -1, -1, -1, -1,
    -1, -1, -1, -1, -1, -1, -1, -1,
    -1, -1, -1, -1, -1, -1, -1, -1,
    -1, -1, -1, -1, -1, -1, -1, -1,
    -1, -1, -1, -1, -1, -1, -1, -1,
    -1, -1, -1, -1, -1, -1, -1, -1};

static const SequenceStep group0SequenceSteps[] = {
    {700, 300, 125, 10000},
    {2000, 1000, 5, 5000}};
static const SequenceStep group1SequenceSteps[] = {
    {250, 250, 50, 0}};

static const uint8_t groupSequenceStepCount[] = {
    (uint8_t)(sizeof(group0SequenceSteps) / sizeof(group0SequenceSteps[0])),
    (uint8_t)(sizeof(group1SequenceSteps) / sizeof(group1SequenceSteps[0]))};

static const SequenceStep *const groupSequences[] = {
    group0SequenceSteps,
    group1SequenceSteps};

// ===== END GENERATED CODE =====

constexpr int numGroups = sizeof(groupSequences) / sizeof(groupSequences[0]);

void setup()
{
    Serial.begin(115200);

    /*
        The TLC5947 BLANK pin keeps all the LEDs off when it is high. The board has
        a pull up resistor on the BLANK pin so the LEDs will be off by default. It is
        important to set all the LEDs to 0 intensity before setting the BLANK pin to
        low so the LEDs do not flash on during start up.
    */

    // turn all LEDs off
    tlc.begin();
    for (uint8_t i = 0; i < NUM_CHANNELS; i++)
    {
        tlc.setPWM(i, 0);
    }
    tlc.write();

    // set blank pin to low
    pinMode(PIN_BLANK, OUTPUT);
    digitalWrite(PIN_BLANK, LOW);
}

unsigned long lastReportMs = 0;
unsigned long loopCount = 0;

void loop()
{
    loopCount++;

    unsigned long now = millis();
    if (now - lastReportMs >= 1000)
    {
        // ~1 second passed
        // Compute Hz based on actual elapsed time to avoid drift
        float hz = (loopCount * 1000.0f) / (now - lastReportMs);

        Serial.print(F("loop() ≈ "));
        Serial.print(hz, 1);
        Serial.println(F(" Hz"));

        loopCount = 0;
        lastReportMs = now;
    }

    for (int group = 0; group < numGroups; group++)
    {
        uint16_t intensity = sequenceIntensity(groupSequences[group], groupSequenceStepCount[group]);
        for (uint8_t well = 0; well < NUM_CHANNELS; well++)
        {
            if (wellGroup[well] == group)
            {
                tlc.setPWM(well, intensity);
            }
        }
    }

    tlc.write();
}

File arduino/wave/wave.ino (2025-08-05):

#include "Adafruit_TLC5947.h"

#define NUM_TLC5947 4             // 96 channels (12 × 8)

#define PIN_DATA   3
#define PIN_CLOCK  5
#define PIN_LATCH  9
#define PIN_OE     6              // set to -1 if not used

Adafruit_TLC5947 tlc(NUM_TLC5947, PIN_CLOCK, PIN_DATA, PIN_LATCH);

// Grid size
const uint8_t ROWS = 8;
const uint8_t COLS = 12;

// ---------- Wave settings ----------
const float     MAX_LEVEL_PCT      = 0.01f;   // 1 % peak
const uint16_t  FRAME_DELAY_MS     = 20;      // ~50 fps
const float     WAVE_PERIOD_MS     = 3000.0f; // time for one full drift
const float     DIAG_WAVELENGTH    = ROWS + COLS; // 20 steps ≈ one sine
const bool      HALF_WAVE          = true;    // off between ridges?
// -----------------------------------

const uint16_t MAX_PWM = (uint16_t)(4095 * MAX_LEVEL_PCT + 0.5f);

// column-major mapping: channel = col*ROWS + row
inline uint8_t chan(uint8_t row, uint8_t col) { return col * ROWS + row; }

void setup() {
  tlc.begin();

  // blank everything before enabling OE
  for (uint8_t ch = 0; ch < 24 * NUM_TLC5947; ++ch) tlc.setPWM(ch, 0);
  tlc.write();

  if (PIN_OE >= 0) {
    pinMode(PIN_OE, OUTPUT);
    digitalWrite(PIN_OE, LOW);          // outputs on (all off right now)
  }
}

// brightness for a given (row,col) at time nowMs
uint16_t diagBrightness(uint8_t row, uint8_t col, uint32_t nowMs) {
  float spatialPhase = 2.0f * PI * (row + col) / DIAG_WAVELENGTH;  // 0‥2π
  float timePhase    = 2.0f * PI * nowMs / WAVE_PERIOD_MS;         // 0‥2π
  float s            = sinf(spatialPhase - timePhase);             // −1‥1

  float norm = HALF_WAVE ? (s > 0.0f ? s : 0.0f)       // bright ridge w/ gaps
                         : 0.5f * (s + 1.0f);          // always glowing

  return (uint16_t)(norm * MAX_PWM + 0.5f);
}

void loop() {
  uint32_t now = millis();

  for (uint8_t col = 0; col < COLS; ++col) {
    for (uint8_t row = 0; row < ROWS; ++row) {
      tlc.setPWM(chan(row, col), diagBrightness(row, col, now));
    }
  }
  tlc.write();
  delay(FRAME_DELAY_MS);
}

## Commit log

2025-06-24 add project
    [RAPC722X.step, led-plate-96-well.kicad_pcb, led-plate-96-well.kicad_sch]
2025-06-25 basic led layout started
    [led-plate-96-well.kicad_pcb, led-plate-96-well.kicad_sch]
2025-06-25 all 96 leds laid out
    [led-plate-96-well.kicad_pcb, led-plate-96-well.kicad_sch]
2025-06-25 basic pcb layout done
    [led-plate-96-well.kicad_pcb]
2025-06-25 auto route done
    [led-plate-96-well.kicad_pcb]
2025-06-25 drill holes, make more compact, re-route
    [led-plate-96-well.kicad_pcb]
2025-06-25 remove right angle
    [led-plate-96-well.kicad_pcb]
2025-06-25 build gerbers
    [led-plate-96-well.kicad_pcb]
2025-06-26 set components and build again
    [led-plate-96-well-CuBottom.gbr, led-plate-96-well-CuTop.gbr, led-plate-96-well-EdgeCuts.gbr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]
2025-06-26 rename project and add second project
    [RAPC722X.step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]
2025-06-26 create basic test pcb
    [RAPC722X.step, basic-test.kicad_pcb, basic-test.kicad_sch]
2025-06-26 fix ciruit
    [basic-test.kicad_pcb, basic-test.kicad_sch]
2025-06-26 re route
    [basic-test.kicad_pcb]
2025-07-02 fix label position
    [basic-4-zone.kicad_pcb]
2025-07-07 create main project
    [A000053.step, RAPC722X.step, led-plate-96-well.kicad_pcb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]
2025-07-10 start main board
    [SMD2835.STEP, led-plate-96-well.kicad_pcb, led-plate-96-well.kicad_sch]
2025-07-10 layout leds
    [Opto Plate v10.step, led-plate-96-well.kicad_pcb, led-plate-96-well.kicad_sch]
2025-07-11 basic layout for all components
    [led-plate-96-well.kicad_pcb]
2025-07-11 finished routing traces
    [led-plate-96-well.kicad_pcb]
2025-07-11 assign parts and fix led driver vias
    [BOM-led-plate-96-well.csv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]
2025-07-30 fix ground vias and re order
    [led-plate-96-well-CuBottom.gbr, led-plate-96-well-CuIn1.gbr, led-plate-96-well-CuIn2.gbr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]
2025-08-20 start redesign as 2 layer board
    [led-plate-96-well.kicad_pcb, led-plate-96-well.kicad_sch]
2025-08-20 fix some part numbers and footprints
    [led-plate-96-well.kicad_pcb, led-plate-96-well.kicad_sch]
2025-08-27 add 96 well plate svg
2025-08-28 start new 96 well plate component
2025-09-02 create simple example arduino program
2025-10-07 basic arduino build servrer
2025-10-14 basic sketch upload button
